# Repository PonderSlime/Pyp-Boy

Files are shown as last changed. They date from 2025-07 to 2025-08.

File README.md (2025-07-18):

# Pip-Boy
Fully-functional recreation of the pip boy from the Fallout franchise. This has features including:
- Pulse oximeter for heart rate
- GPS for location tracking
- RTL-SDR for hacking the radio waves

I decided to build this project because I had recently came across Fallout 4, which quickly rose to my top 5 video games list. When Highway was annouced, I decided I should build something from it. I had two options: build power armor (which would cost way too much, and is already being done by Hacksmith Industries), or the Pip-Boy (which is much more achievable for several reasons, cost included). Of course I chose the Pip-Boy, because It is still a really cool piece of tech. Another reason to build this was because I thought it would be really cool to navigate an entire system with just knobs, and one button.

**Onshape Link:** [https://cad.onshape.com/documents/fef0e9c1c845178b6cc354c6/w/e4e098e2dc3ae20b4478296f/e/bf3082dc19ffc9c7d7482000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](https://cad.onshape.com/documents/fef0e9c1c845178b6cc354c6/w/e4e098e2dc3ae20b4478296f/e/bf3082dc19ffc9c7d7482000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)

## Screenshots
Here's the 3D cad model:

https://hc-cdn.hel1.your-objectstorage.com/s/v3/2ecbe588889400ed564f8305abd84febf3086739_2025-06-28-181544_hyprshot.png

Here's the wiring diagram of the components used:

https://hc-cdn.hel1.your-objectstorage.com/s/v3/c522e84e316c760e37cd8d82a66ab6b510f91d17_2025-07-05-164655_hyprshot.png

## BOM:

| Part | Qty | Link | Price |
|---|-----|---|---|
| Raspberry Pi Zero 2 (Already have) | 1 | https://www.adafruit.com/piz2w | 16.50 |
| 4.0 Inch Waveshare HDMI Display | 1 | https://www.amazon.com/HDMI-LCD-Resolution-Resistive-Screen/dp/B07P5H2315 | 38.99 |
| V4 RTL-SDR Module | 1 | https://www.amazon.com/RTL-SDR-Blog-RTL2832U-Software-Defined/dp/B0CD745394 | 37.95 |
| GY-NEO6MV2 NEO-6M GPS Module | 1 | https://www.amazon.com/DWEII-GY-NEO6MV2-NEO6MV2-Control-Antenna/dp/B0BBM2H5TX/ | 8.99 |
| MAX10302 Pulse Oximeter | 1 | https://www.amazon.com/HiLetgo-MAX30102-Breakout-Oximetry-Solution/dp/B07QC67KMQ/ | 6.99 |
| Lithium Ion Battery - 3.7V 10050mAh | 1 | https://www.digikey.com/en/products/detail/adafruit-industries-llc/5035/14625568 | 29.95 |
| Power Boost 1000 Charger | 1 | https://www.digikey.com/en/products/detail/adafruit-industries-llc/2465/5356834 | 19.95 |
| EC12 Encoder | 5 | https://www.digikey.com/en/products/detail/alps-alpine/EC12E24204A2/19529077 | 8.40 |
| Push Button | 1 | https://www.digikey.com/en/products/detail/c-k/PVA1-OA-H1-1-2N-V2/417717 | 2.40 |
| 3mm Diameter 50mm Steel Dowel Pin | 2 | https://www.amazon.com/uxcell-Stainless-Support-Fasten-Elements/dp/B07MDFSJJ1 | 6.69 |
| 3mm Diameter 16mm Steel Dowel Pin | 2 | https://www.amazon.com/uxcell-Straight-Retaining-Stainless-Elements/dp/B01MQJAUUC | 6.69 |
| 3mm Diameter 7mm Steel Dowel Pin | 2 | https://www.amazon.com/HARFINGTON-Stainless-Cylindrical-Furniture-Installation/dp/B0F6CZV1MH | 6.09 |
| 3mm Diameter 36mm Steel Dowel Pin (Already have) | 1 | https://www.amazon.com/uxcell-Cylindrical-Mechanical-Manufacturing-Installation/dp/B0DRS9VZR4 | 6.99 |
| M3x4mmx5mm Heatset Inserts (Already have) | 6 | https://www.amazon.com/Threaded-Inserts-Printing-Components-Assortment/dp/B0DGQH7YX6 | 7.09 |
| M3 Screw Kit (whatever screw length works) (Already have) | 1 | https://www.amazon.com/Assortment-Stainless-Replacement-Machine-Fastener/dp/B0CMQG542V | 15.99 |
| 2 Gallon Polypropylene Container (for electroplating) | 1 | https://www.mcmaster.com/products/tubs/food-industry-plastic-storage-containers-6/material~polypropylene/ | 9.19 |
| Polypropylene Carboy (Copper Sulfate solution storage) | 1 | https://www.mcmaster.com/products/tanks/capacity~3-gal/carboys-1~/ | 31.29 |
| Copper sulfate Pentahydrate | 1 | https://www.amazon.com/Copper-Sulfate-Pentahydrate-Powder-Lbs/dp/B018W893PY/ | 22.95 |
| Distilled Water | 2 | https://www.walmart.com/ip/Pure-Life-Distilled-Water-1-Gallon-Plastic-Bottled-Water-1-Pack-Side-Handle/1070666864 | 2.38 |
| Distilled White Vinegar | 2 | https://www.walmart.com/ip/Great-Value-Distilled-White-Vinegar-128-fl-oz/10450998 | 3.94 |
| Metal Polish | 1 | https://www.amazon.com/Brasso-2660089334-Multi-Purpose-Metal-Polish/dp/B00D600PLA/ | 4.98 |
| ELECTRONICS+OTHER PARTS SUBTOTAL: | | | $189.89 |
| ELECTROPLATING SUBTOTAL (Can't do because of funds): | | | $79.67 |
| SUBTOTAL+ELECTROPLATING: | | | $269.56 |
| SUBTOTAL WITHOUT ELECTROPLATING: | | | $189.89 |
| TAX: | | | $21.99 |
| SUBTOTAL+SHIPPING/TAX: | | | 211.88 |
| WHAT I WILL BUY/ALREADY HAVE: | | | $68.56 |
| COST FOR HACK CLUB: | | | $143.32 (If this gets approved as 10 points, then I want to get the electroplating gear) |

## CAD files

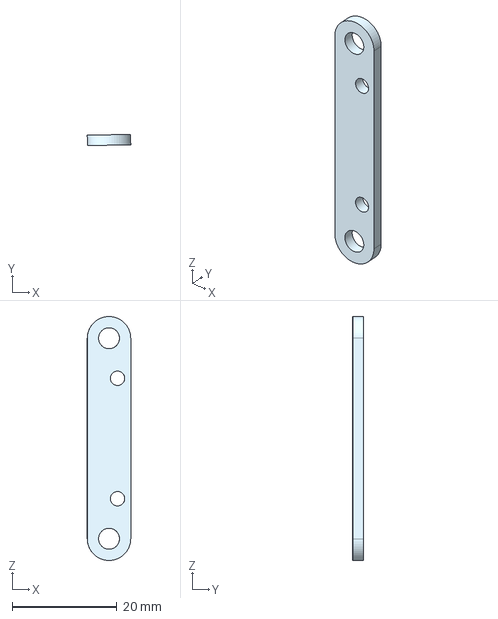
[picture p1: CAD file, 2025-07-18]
Pyp-Boy CAD Models/PyP-Boy Finished CAD Files/Part Studio 1 - RPI Zero Mounting Bracket 2.step
8.31 x 2.05 x 46.6 mm

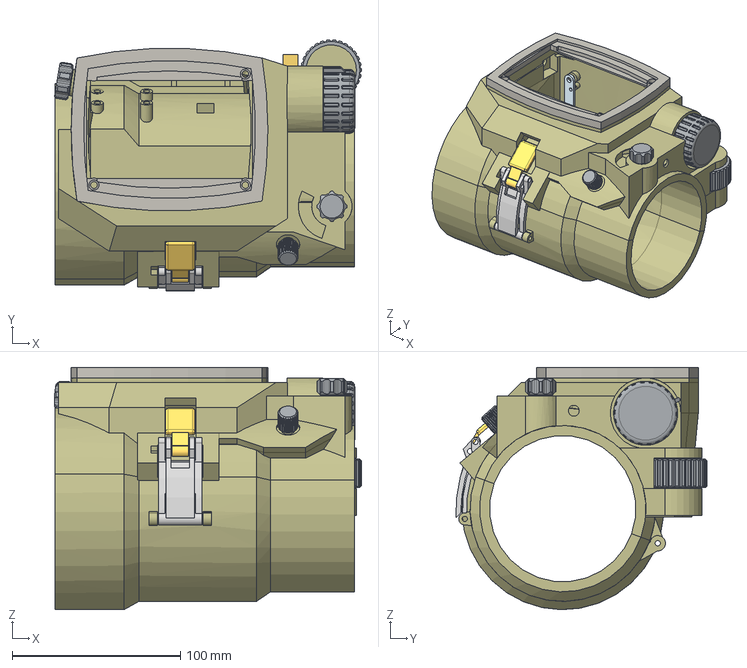
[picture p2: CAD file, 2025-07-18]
Pyp-Boy CAD Models/PyP-Boy FInished CAD Model.step
182.5 x 149.3 x 144.0 mm

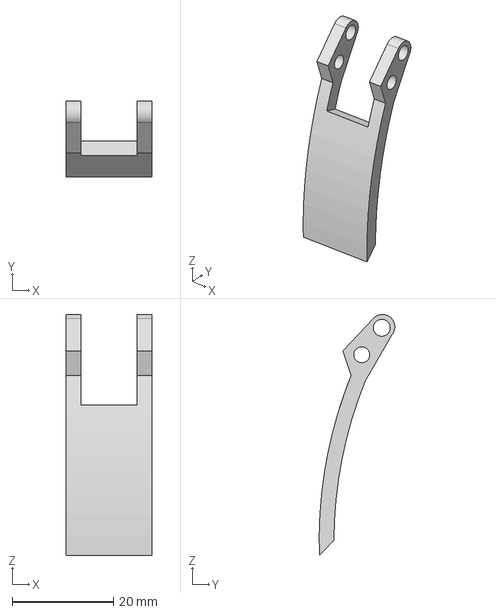
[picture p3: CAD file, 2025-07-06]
Pyp-Boy CAD Models/Part Studio 1 - Latch Handle.step
17.0 x 15.0 x 47.7 mm

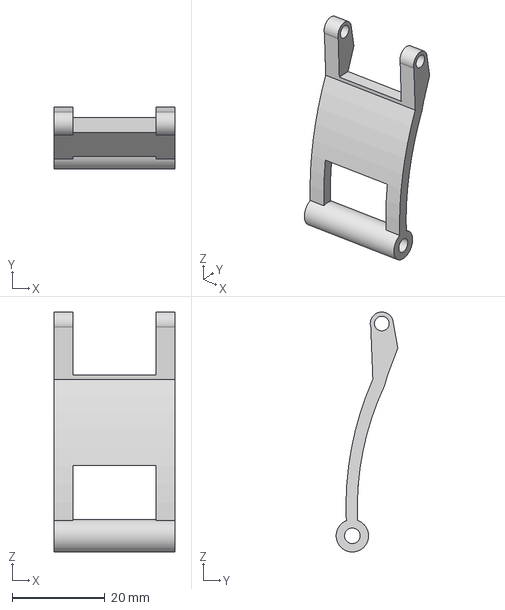
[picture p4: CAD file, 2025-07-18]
Pyp-Boy CAD Models/PyP-Boy Finished CAD Files/Part Studio 1 - Latch Base.step
26.0 x 13.3 x 51.8 mm

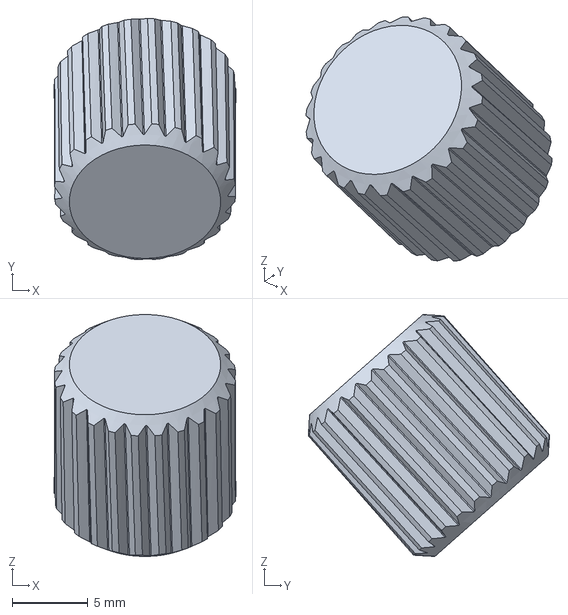
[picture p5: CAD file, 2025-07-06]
Pyp-Boy CAD Models/Part Studio 1 - Left-Right Control Knob.step
12.0 x 15.9 x 16.0 mm

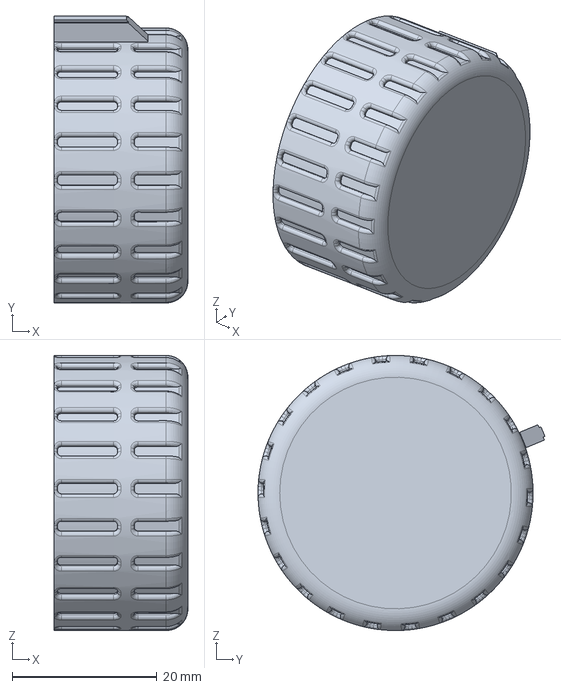
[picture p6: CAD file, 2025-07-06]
Pyp-Boy CAD Models/Part Studio 1 - Primary Menu Nav Wheel.step
18.5 x 39.6 x 38.0 mm

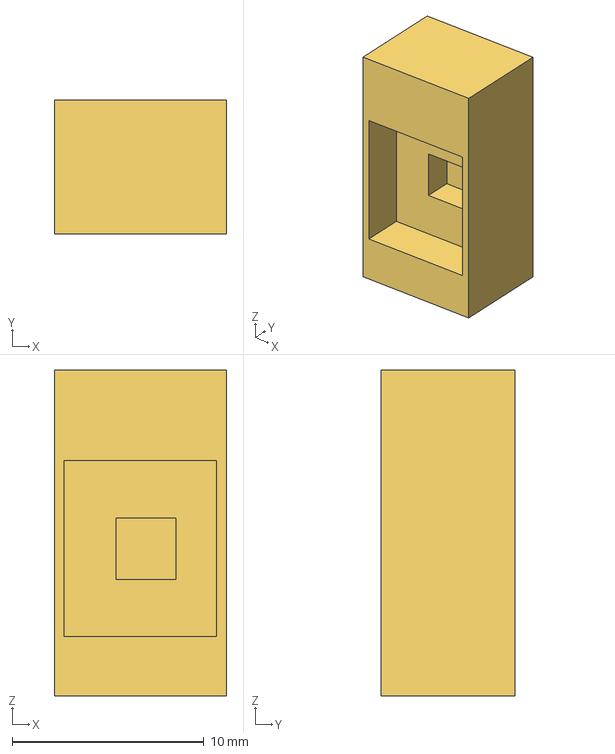
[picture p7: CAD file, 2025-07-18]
Pyp-Boy CAD Models/PyP-Boy Finished CAD Files/Part Studio 1 - Menu Select Button.step
9.00 x 7.00 x 17.0 mm

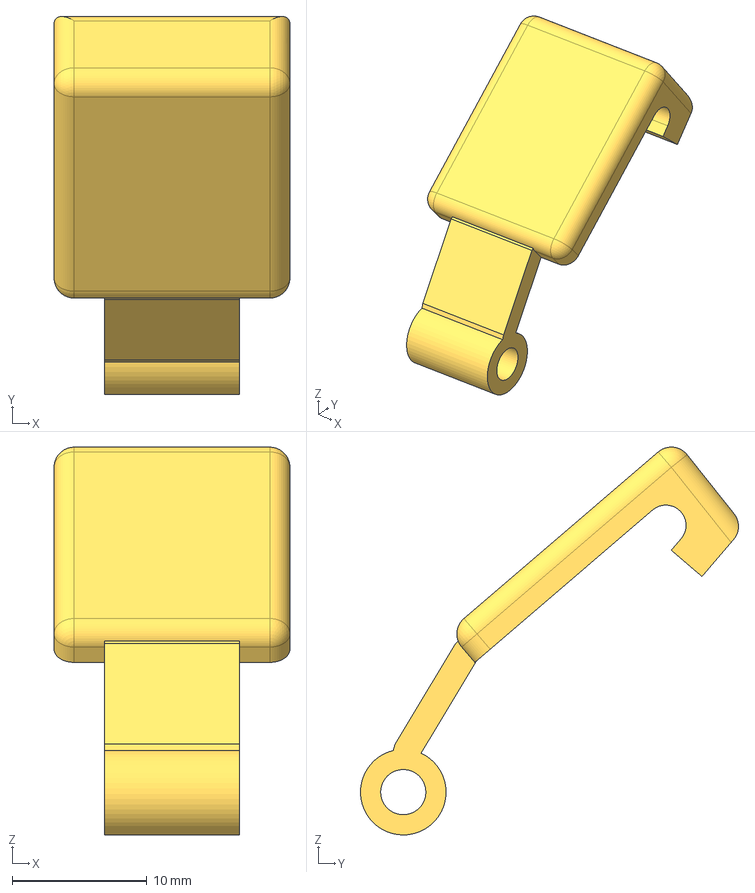
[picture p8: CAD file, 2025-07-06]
Pyp-Boy CAD Models/Part Studio 1 - Latch Hook.step
17.5 x 28.0 x 28.8 mm

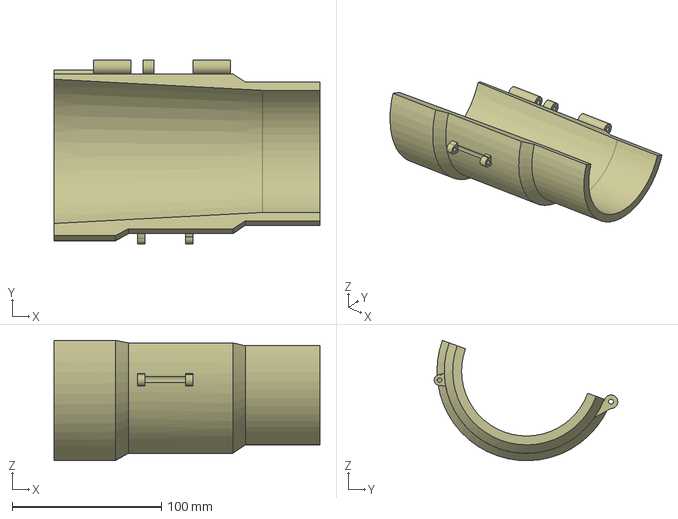
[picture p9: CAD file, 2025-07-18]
Pyp-Boy CAD Models/PyP-Boy Finished CAD Files/Part Studio 1 - Arm Back.step
178.0 x 122.9 x 80.5 mm

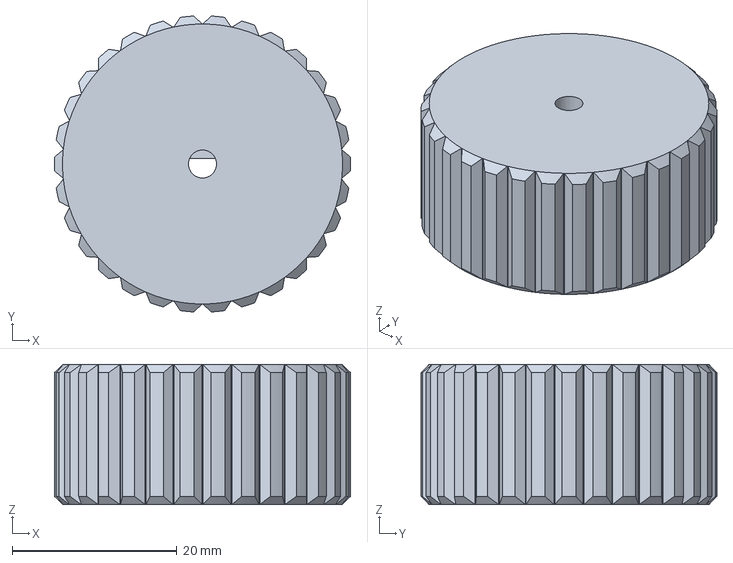
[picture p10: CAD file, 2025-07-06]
Pyp-Boy CAD Models/Part Studio 1 - Secondary Menu Nav Wheel.step
36.0 x 35.9 x 17.0 mm

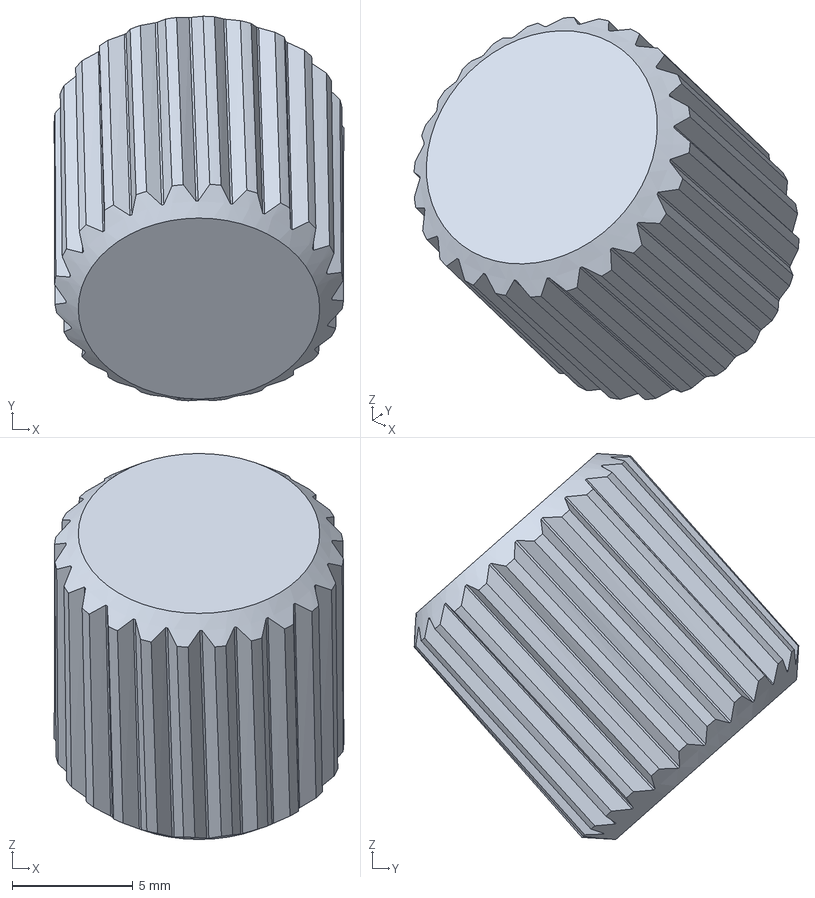
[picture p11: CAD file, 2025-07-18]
Pyp-Boy CAD Models/PyP-Boy Finished CAD Files/Part Studio 1 - Left-Right Control Knob.step
12.0 x 15.9 x 16.0 mm

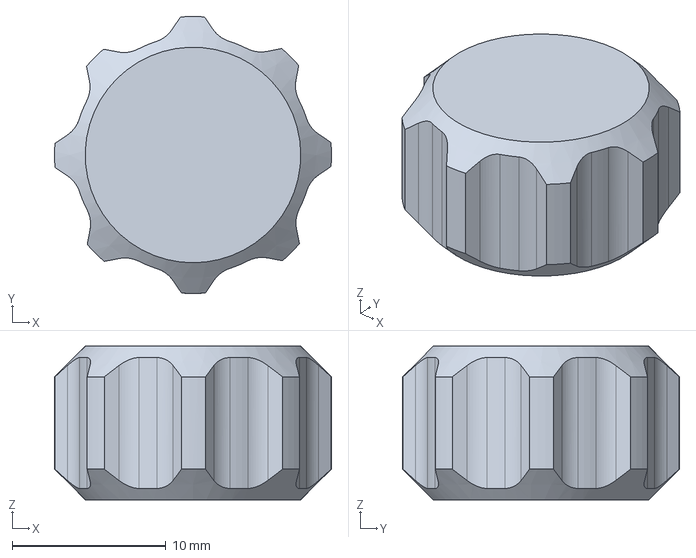
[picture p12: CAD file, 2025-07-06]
Pyp-Boy CAD Models/Part Studio 1 - Radio Tuner Dial.step
18.0 x 18.0 x 10.0 mm

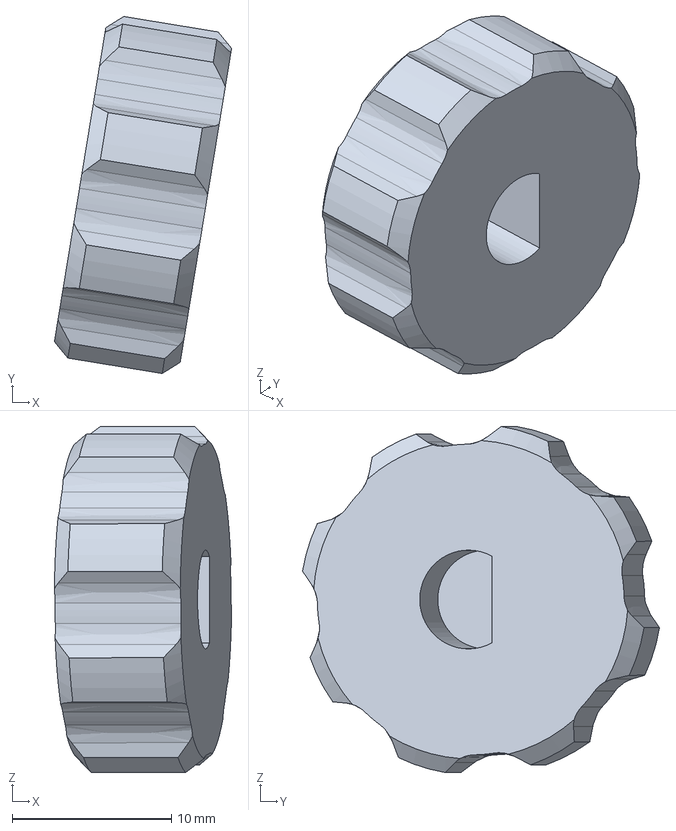
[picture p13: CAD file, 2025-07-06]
Pyp-Boy CAD Models/Part Studio 1 - Up-Down Control Knob.step
11.1 x 22.4 x 21.7 mm

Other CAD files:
Pyp-Boy CAD Models/PyP-Boy Finished CAD Files/Part Studio 1 - RPI Zero Mounting Bracket 1.step
Pyp-Boy CAD Models/PyP-Boy Finished CAD Files/Part Studio 1 - Latch Handle.step
Pyp-Boy CAD Models/Part Studio 1 - Latch Base.step
Pyp-Boy CAD Models/PyP-Boy Finished CAD Files/Part Studio 1 - Latch Hook.step
Pyp-Boy CAD Models/PyP-Boy Finished CAD Files/Part Studio 1 - Up-Down Control Knob.step
Pyp-Boy CAD Models/Part Studio 1 - Arm Back.step
Pyp-Boy CAD Models/PyP-Boy Finished CAD Files/Part Studio 1 - Arm Front.step
Pyp-Boy CAD Models/PyP-Boy Finished CAD Files/Part Studio 1 - Electronic Housing Rear Plate.step
Pyp-Boy CAD Models/PyP-Boy Finished CAD Files/Part Studio 1 - Electronic Housing.step
Pyp-Boy CAD Models/PyP-Boy Finished CAD Files/Part Studio 1 - Primary Menu Nav Wheel.step
Pyp-Boy CAD Models/PyP-Boy Finished CAD Files/Part Studio 1 - Radio Tuner Dial.step
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

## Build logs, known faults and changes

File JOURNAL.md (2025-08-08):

---
title: "Pyp-Boy"
author: "Micah Edwards"
description: "Fully-Functional recreation of the Pip-Boy 3000 Mark IV from Fallout 4"
created_at: "2025-05-22"
---
## Total time spent: 25h

# May 22nd-23rd: Started on Modeling the housing!

Did a bit of research on the size of the Pip Boy is, and started modeling it in Onshape.
I figured out how to use some tools I haven't used before, including the wrap tool and split tool. The base shape of the Pip-Boy is somewhat complete, but I still have a long way to go until I am done with the polished design (still need to add a ton of details, knobs, screw holes, vents, and many other things.)

https://hc-cdn.hel1.your-objectstorage.com/s/v3/68417295fe4105d7c07525d4ab1f006cc605584a_2025-05-23-143347_hyprshot.png

**Time spent: 3h**

# May 23rd-24th: Added some knobs!
I started to model where each of the knobs will go on the Pip-Boy. Also, I fixed some of the form factor of the overall arm section. I didn't really do a ton though

**Time spent: 2h**

# May 26th: Continuing knobby things
I added a knob for secondary menu selection and radio tuning, as well as a select button and a radio tuner indicator spot

https://hc-cdn.hel1.your-objectstorage.com/s/v3/095caf989e5443e84d2df1f08b7d26e1f4534526_2025-05-26-155143_hyprshot.png
https://hc-cdn.hel1.your-objectstorage.com/s/v3/43221945aa9acdee51f7f8d1b4c205f1dce9f17a_2025-05-26-155139_hyprshot.png

**Time spent: 2h**

# May 27th: Finished knobby stuff
I added both of the navigation wheels, as well as split apart the tube and electronics housing sections.

**Time spent: 1h**

# May 28th: Started Latch Mechanism, Arm Erginomics
I started work on the latch mecanism for the Pip-Boy, and also turned the cylendrical interior of the model into more of a cone shape.

https://hc-cdn.hel1.your-objectstorage.com/s/v3/961e35072b154a81121447986b809b8d1c70d7fe_2025-05-28-200431_hyprshot.png
https://hc-cdn.hel1.your-objectstorage.com/s/v3/486bc97e55d4ada4199406a0d993f4b2aa87ab2b_2025-05-28-200417_hyprshot.png

**Time spent: 1h**

# June 27th: Back From Break, Finished Latch Mechanism & Hinges, Added Encoder and Heatset Mounting Holes
I finally got the motivation to continue working on my project. I finished uo the latch mechanism and the upper hinge with some 3mm rods. Also, I added spots for the encoders on all of the knobs. In addition, I added a handful of heatset holes that are hidden from the frontside to secure it together.

https://hc-cdn.hel1.your-objectstorage.com/s/v3/b2e52c3f80351a633573ffb4218ada6e2fc150f8_2025-06-27-203610_hyprshot.png
https://hc-cdn.hel1.your-objectstorage.com/s/v3/75f5c39bce37d8ea9c7e3828193f0c434625de04_2025-06-27-203554_hyprshot.png
https://hc-cdn.hel1.your-objectstorage.com/s/v3/76d50b34b40de67969643d15641455e24a616dab_2025-06-27-203549_hyprshot.png

**Time spent: 4h**

# June 28th: Added Texture to the Knobs, did Research on RTL-SDR Modules
I added some nice details to each of the knobs, and gave them cool grips. Also, I fixed the latch tolerances so they actually work, and did some research on how I could get FM radio recieving on my device.
https://hc-cdn.hel1.your-objectstorage.com/s/v3/2ecbe588889400ed564f8305abd84febf3086739_2025-06-28-181544_hyprshot.png

**Time spent: 3h**

# June 29th: Started Work on a BOM, Added Latch Pin Slot, Manufacturing Research
Today I decided to start working on a bill of materials for my project. I also took some time to figure out where/how I should get the case manufactured. After trying several CNC companies' auto quote, I determined that it would be way too expensive ($30.00 USD for just one simple latch part!). Instead, I will 3D print the parts and electroplate it at home. The only change I made to the CAD model today was adding a latch pin slot so that the latch can actually lock properly.

https://hc-cdn.hel1.your-objectstorage.com/s/v3/1c74663c2242f76f8d4dc3c0941211fc3dfbe883_2025-06-29-171235_hyprshot.png

**Time spent: 2h**

# July 1-2nd: Started work on pyp-tui
I decided that I wanted to code a TUI (terminal user interface) using rust, to use as the main interface for my device. So far I have a basic inventory database, menus, and submenus. It still need some controls for the RTL-SDR module though.

https://hc-cdn.hel1.your-objectstorage.com/s/v3/79f344e348c653453cdb9142933b67766726bf15_2025-07-02-152713_hyprshot.png

**Time spent: 2h**

# July 3-4: Working on Organization, Adding Map Data
I decided to start organizing my script, by breaking it up into seperate files. Also, I was able to finally get the map data stuff working. Origonally, I was going to go for a ascii art map centered on the coordinates from the gps module, but I couldn't get that working. It will just be data instead. And the best part? It works offline, with a small library size! Also, I implemented an escape button that erases any evidence of the tui being open! In addition, I fixed the inventory tabs so that they change content based on category.

https://github.com/user-attachments/assets/03545f6d-08a7-4fc2-ad75-7554e2540552

**Time spent: 5h**

# July 16-20: Case Design Fixes and Assembly
I finally got all the parts for my project! I started by fixing all of my case design files so that they could fit my components. This took about four hours, and I modified the encoder holes so they could fit more snugly, added mounting posts for the raspberry pi and gps module, and added a nice cutout for my battery and wiring stuff. I also worked a bit on assembling my project, and got everything put together!

https://hc-cdn.hel1.your-objectstorage.com/s/v3/0b8f877d28e4e5ec8f6f84db51e3453ea9cfeb9f_2025-07-20-210547_hyprshot.png
https://hc-cdn.hel1.your-objectstorage.com/s/v3/38d9a39f9074412fb17914c7675049f7af02daad_2025-07-20-210528_hyprshot.png





**Time spent: 7h**

# August 5-7th: Finished Assembly
I finally finished assembly, after getting the last part for the screen. Also, I fixed the inventory system's quantity system, because it had a glitch with the differences between the json and the filtered lists. 

**Time spent: 1h**

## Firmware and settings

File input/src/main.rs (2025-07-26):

// src/main.rs

use rppal::gpio::{Gpio, InputPin, Level};

use evdev::{Key, InputEvent, EventType, AttributeSet}; // Add AttributeSet import
use evdev::uinput::{VirtualDevice, VirtualDeviceBuilder};

use std::sync::{Arc, Mutex};
use std::time::{Duration, Instant};
use std::thread;
use anyhow::{Result, Context};
use log::{info, debug};
use env_logger;

// Define GPIO pins for each encoder and the main button
const ENCODER_PINS: [(u8, u8); 5] = [
    (17, 27), // Encoder 1: Out A (CLK), Out B (DT)
    (23, 24), // Encoder 2
    (5, 6),   // Encoder 3
    (19, 26), // Encoder 4
    (20, 21), // Encoder 5
];

const MAIN_BUTTON_PIN: u8 = 10; // For the 2-pin button

// Structure to hold encoder state
struct Encoder {
    pin_a: InputPin,
    pin_b: InputPin,
    last_state_a: Level,
}

impl Encoder {
    fn new(gpio: &Gpio, pin_a_num: u8, pin_b_num: u8) -> Result<Self> {
        // Use into_input_pullup() directly on the Pin to set pull-up and convert to InputPin
        let pin_a = gpio.get(pin_a_num)?.into_input_pullup();
        let pin_b = gpio.get(pin_b_num)?.into_input_pullup();

        let initial_state_a = pin_a.read();

        Ok(Encoder {
            pin_a,
            pin_b,
            last_state_a: initial_state_a,
        })
    }

    fn update(&mut self) -> Option<i8> {
        let current_state_a = self.pin_a.read();
        let current_state_b = self.pin_b.read();

        if current_state_a != self.last_state_a {
            self.last_state_a = current_state_a;
            if current_state_a == Level::Low {
                if current_state_b == Level::Low {
                    return Some(1); // Clockwise
                } else {
                    return Some(-1); // Counter-clockwise
                }
            }
        }
        None
    }
}


fn main() -> Result<()> {
    env_logger::Builder::from_env(env_logger::Env::default().default_filter_or("info")).init();
    info!("Starting Raspberry Pi Encoder Input service...");

    let gpio = Gpio::new().context("Failed to initialize GPIO")?;

    // --- Setup Encoders ---
    let mut encoders: Vec<Encoder> = Vec::with_capacity(ENCODER_PINS.len());
    for (i, &(pin_a_num, pin_b_num)) in ENCODER_PINS.iter().enumerate() {
        let encoder = Encoder::new(&gpio, pin_a_num, pin_b_num)
            .with_context(|| format!("Failed to set up encoder {}", i + 1))?;
        encoders.push(encoder);
        info!("Encoder {} (GPIO {}/{}) configured.", i + 1, pin_a_num, pin_b_num);
    }

    // --- Setup Main Button ---
    // Use into_input_pullup() directly on the Pin to set pull-up and convert to InputPin
    let main_button_pin = gpio.get(MAIN_BUTTON_PIN)?.into_input_pullup();
    info!("Main Button (GPIO {}) configured.", MAIN_BUTTON_PIN);

    // --- Setup evdev Virtual Device ---
    let uinput_device = Arc::new(Mutex::new(
        VirtualDeviceBuilder::new()?
            .name("EC12 Multi-Encoder Keyboard")
	    // Use AttributeSet::from_iter for with_keys in 0.12.2
            .with_keys(&AttributeSet::from_iter(vec![
                // Encoder 1: Left/Right
                Key::KEY_LEFT, Key::KEY_RIGHT,
                // Encoder 2: Up/Down
                Key::KEY_UP, Key::KEY_DOWN,
                // Encoder 3: A/D
                Key::KEY_A, Key::KEY_D,
                // Encoder 4: W/S
                Key::KEY_W, Key::KEY_S,
                // Encoder 5: KPPLUS/KPMINUS
                Key::KEY_KPPLUS, Key::KEY_KPMINUS,
                // Main Button: Enter
                Key::KEY_ENTER,
            ]))?
            .build()
            .context("Failed to build virtual device")?
    ));
    info!("Virtual input device created.");

    // --- Event loop for Encoders ---
    let mut handles = Vec::new();
    for (i, mut encoder) in encoders.into_iter().enumerate() {
        let uinput_device_clone: Arc<Mutex<VirtualDevice>> = Arc::clone(&uinput_device);
        let key_map = match i {
            0 => (Key::KEY_LEFT, Key::KEY_RIGHT), // Encoder 1: Left/Right
            1 => (Key::KEY_UP, Key::KEY_DOWN),    // Encoder 2: Up/Down
            2 => (Key::KEY_A, Key::KEY_D),        // Encoder 3: A/D
            3 => (Key::KEY_W, Key::KEY_S),        // Encoder 4: W/S
            4 => (Key::KEY_KPPLUS, Key::KEY_KPMINUS), // Encoder 5: KPPLUS/KPMINUS
            _ => unreachable!(),
        };

        let handle = thread::spawn(move || -> Result<()> {
            let mut last_detection_time = Instant::now();
            let debounce_delay = Duration::from_millis(5);

            loop {
                thread::sleep(Duration::from_micros(100));

                if last_detection_time.elapsed() < debounce_delay {
                    continue;
                }

                if let Some(direction) = encoder.update() {
                    let mut device = uinput_device_clone.lock().unwrap();
                    if direction == 1 {
                        debug!("Encoder {} Clockwise: {:?}", i + 1, key_map.0);
                        device.emit(&[
                            InputEvent::new(EventType::KEY, key_map.0.0, 1), // Pass EventType::KEY directly
                            InputEvent::new(EventType::KEY, key_map.0.0, 0), // Pass EventType::KEY directly
                        ])?;
                    } else {
                        debug!("Encoder {} Counter-Clockwise: {:?}", i + 1, key_map.1);
                        device.emit(&[
                            InputEvent::new(EventType::KEY, key_map.1.0, 1), // Pass EventType::KEY directly
                            InputEvent::new(EventType::KEY, key_map.1.0, 0), // Pass EventType::KEY directly
                        ])?;
                    }
                    last_detection_time = Instant::now();
                }
            }
        });
        handles.push(handle);
    }

    // --- Event loop for Main Button ---
    let uinput_device_clone: Arc<Mutex<VirtualDevice>> = Arc::clone(&uinput_device);
    let button_handle = thread::spawn(move || -> Result<()> {
        let mut last_state = main_button_pin.read();
        let mut last_press_time = Instant::now();
        let debounce_delay = Duration::from_millis(50);

        loop {
            thread::sleep(Duration::from_millis(10));
            let current_state = main_button_pin.read();

            if current_state != last_state {
                if last_press_time.elapsed() < debounce_delay {
                    continue;
                }

                last_state = current_state;
                if current_state == Level::Low { // Button pressed (pulled to ground)
                    info!("Main Button Pressed: KEY_ENTER!");
                    let mut device = uinput_device_clone.lock().unwrap();
                    device.emit(&[
                        InputEvent::new(EventType::KEY, Key::KEY_ENTER.0, 1), // Pass EventType::KEY directly
                        InputEvent::new(EventType::KEY, Key::KEY_ENTER.0, 0), // Pass EventType::KEY directly
                    ])?;
                }
                last_press_time = Instant::now();
            }
        }
    });
    handles.push(button_handle);


    // Wait for all threads to finish (they won't in this case, it's a daemon)
    for handle in handles {
        handle.join().expect("Thread panicked")?;
    }

    info!("Service stopped.");
    Ok(())
}

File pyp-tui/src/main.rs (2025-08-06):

use chrono::prelude::*;
use crossterm::{
    event::{self, DisableMouseCapture, EnableMouseCapture, Event as CEvent, KeyCode},
	execute,
    terminal::{disable_raw_mode, enable_raw_mode, EnterAlternateScreen, LeaveAlternateScreen},
};
use rand::{distributions::Alphanumeric, prelude::*};

use std::fs;
use std::io;
use std::sync::mpsc;
use std::thread;
use std::time::{Duration, Instant};
use std::error::Error as StdError;
use thiserror::Error;
use ratatui::{
    backend::CrosstermBackend,
    layout::{Alignment, Constraint, Direction, Layout},
    style::{Color, Modifier, Style},
    text::{Span, Line, Text},
    widgets::{Block, BorderType, Borders, ListState, Paragraph, Tabs},
    Terminal,
    Frame,
};

use gpsd_client::*;

extern crate linux_embedded_hal as hal;
extern crate max3010x;
extern crate ratatui;

use max3010x::{Max3010x, Led, SampleAveraging};

const DB_PATH: &str = "./data/db.json";

mod render_tabs;
mod menus;
mod kb;

use render_tabs::{render_map, render_stat, render_data, render_inv, read_db, get_map_data, Item, add_item_to_db, show_quantity_selector,};
use menus::{MenuItem, StatSubMenu, InvSubMenu, DataSubMenu};

#[derive(Error, Debug)]
pub enum Error {
    #[error("error reading the DB file: {0}")]
    ReadDBError(#[from] io::Error),
    #[error("error parsing the DB file: {0}")]
    ParseDBError(#[from] serde_json::Error),
}

enum Event<I> {
    Input(I),
    Tick,
}
#[derive(Debug, PartialEq)]
pub struct Coordinates {
    pub latitude: f64,
    pub longitude: f64,
}
pub fn get_current_coordinates_array() -> Result<[f64; 2], Box<dyn StdError>> {
    let mut gps = GPS::connect()
    	.map_err(|e| Box::<dyn StdError>::from(format!("GPS connect error: {:?}", e)))?;
	let data: GPSData = gps.current_data()
    	.map_err(|e| Box::<dyn StdError>::from(format!("GPS data error: {:?}", e)))?;
	if data.lat.is_finite() && data.lon.is_finite() {
    	Ok([data.lat, data.lon])
	} else {
		Err(Box::new(io::Error::new(
			io::ErrorKind::NotFound,
			"Latitude or longitude invalid in GPS data",
		)))
	}
}
fn main() -> Result<(), Box<dyn std::error::Error>> {
	
	let coords: [f64; 2] = match get_current_coordinates_array() {
        Ok(c) => c,
        Err(e) => {
            eprintln!("Error getting coordinates: {}", e);
            [0.0, 0.0]
        }
    };

	let mut map_data: Option<String> = None;
	let mut start_time = Instant::now();
    let one_minute = Duration::from_secs(60);

	if map_data.is_none() || start_time.elapsed() >= one_minute {
		start_time = Instant::now();
        map_data = Some(get_map_data(coords));
		println!("getting map data: {:?}", map_data)
    }

	let stat_submenu_titles = vec!["GENERAL", "STATUS", "SETTINGS"];
	let inv_submenu_titles = vec!["WEAPONS", "APPAREL", "AID", "MISC", "JUNK", "MODS", "AMMO"];
	let data_submenu_titles = vec!["QUESTS", "WORKSHOPS", "STATS"];

	let mut active_stat_submenu = StatSubMenu::General;
	let mut active_inv_submenu = InvSubMenu::Weapons;
	let mut active_data_submenu = DataSubMenu::Quests;


    enable_raw_mode().expect("can run in raw mode");
	let mut stdout = io::stdout();

	execute!(stdout, EnterAlternateScreen, EnableMouseCapture)?;
	

    let (tx, rx) = mpsc::channel();
    let tick_rate = Duration::from_millis(200);
    thread::spawn(move || {
        let mut last_tick = Instant::now();
        loop {
            let timeout = tick_rate
                .checked_sub(last_tick.elapsed())
                .unwrap_or_else(|| Duration::from_secs(0));

            if event::poll(timeout).expect("poll works") {
                if let CEvent::Key(key) = event::read().expect("can read events") {
                    tx.send(Event::Input(key)).expect("can send events");
                }
            }

            if last_tick.elapsed() >= tick_rate {
                if let Ok(_) = tx.send(Event::Tick) {
                    last_tick = Instant::now();
                }
            }
        }
    });

    let stdout = io::stdout();
    let backend = CrosstermBackend::new(stdout);
    let mut terminal = Terminal::new(backend)?;
    terminal.clear()?;

    let menu_titles = vec!["STAT", "INV", "DATA", "MAP", "RADIO"];
    let mut active_menu_item = MenuItem::Stat;
    let mut inv_list_state = &mut ListState::default();
    inv_list_state.select(Some(0));

	/* let dev = hal::I2cdev::new("/dev/i2c-1").unwrap();

	let mut sensor = Max3010x::new_max30102(dev);
	let mut sensor = sensor.into_heart_rate().unwrap();
	sensor.set_sample_averaging(SampleAveraging::Sa4).unwrap();
	sensor.set_pulse_amplitude(Led::All, 15).unwrap();
	sensor.enable_fifo_rollover().unwrap();

	let mut data = [0; 3];
	let samples_read = sensor.read_fifo(&mut data).unwrap();

  	let dev = sensor.destroy(); */

    loop {
		terminal.clear();
        terminal.draw(|rect| {
            let size = rect.area();
			
            let chunks = Layout::default()
                .direction(Direction::Vertical)
                .margin(2)
                .constraints(
                    [
                        Constraint::Length(3),
                        Constraint::Min(2),
                        Constraint::Length(3),
                    ]
                    .as_ref(),
                )
                .split(size);
			
            let copyright = Paragraph::new("COPYRIGHT 2075 ROBCO(R)")
                .style(Style::default().fg(Color::LightCyan))
                .alignment(Alignment::Center)
                .block(
                    Block::default()
                        .borders(Borders::ALL)
                        .style(Style::default().fg(Color::White))
                        .title("COPYRIGHT")
                        .border_type(BorderType::Plain),
                );

            let menu: Vec<Line> = menu_titles
                .iter()
                .map(|t| {
                    let (first, rest) = t.split_at(1);
                    Line::from(vec![
                        Span::styled(
                            first,
                            Style::default()
                                .fg(Color::Yellow)
                                .add_modifier(Modifier::UNDERLINED),
                        ),
                        Span::styled(rest, Style::default().fg(Color::White)),
                    ])
                })
                .collect();
			
            let tabs = Tabs::new(menu)
                .select(Some(active_menu_item.into()))
                .block(Block::default().title("STAT").borders(Borders::ALL))
                .style(Style::default().fg(Color::White))
                .highlight_style(Style::default().fg(Color::Yellow))
                .divider(Span::raw("|"));
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

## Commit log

2025-06-28 Got back from break, finished hinges and encoder knob mountings
2025-06-29 June 28th: Added Texture to Knobs, Fixed Hinge Tolerances
2025-06-29 Added Initial BOM.csv
    [BOM.csv]
2025-06-29 June 29th: Added Latch Pin Slot
2025-07-04 Reverted OSM_Geo_Mapper, using data-based mapping (timezones added)
    [main.rs]
2025-07-05 Added "+ Add New" button to inventory
2025-07-06 Added Wiring, first full BOM
    [BOM.csv, Pip Boy wiring.kicad_pcb, Pip Boy wiring.kicad_sch]
2025-07-06 Auto stash before merge of "main" and "origin/main"
    [BOM.csv]
2025-07-06 Fixed something on the total bar
    [BOM.csv]
2025-07-06 Fixed final price guestimate (excluding shipping :C )
    [BOM.csv]
2025-07-06 Added all cad models from Onshape, did more number crunching for price
    [BOM.csv, Part Studio 1 - Arm Back.step, Part Studio 1 - Arm Front.step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]
2025-07-06 Fixed prices to match that of a 6-point project, added full step file
    [BOM.csv, Pyp-Boy CAD Model.step]
2025-07-06 Fixed error in BOM.csv line 13
    [BOM.csv]
2025-07-06 Fixed another error in BOM.csv
    [BOM.csv]
2025-07-06 Updated README.md BOM Table
2025-07-18 Finished adding all mounting points to CAD Model
    [Part Studio 1 - Arm Back.step, Part Studio 1 - Arm Front.step, Part Studio 1 - Electronic Housing Rear Plate.step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]
2025-07-19 Partially completed keyboard in tui, added encoders to wiring diagram
    [Pip Boy wiring.kicad_sch]
2025-07-21 Assembled Project!
2025-07-21 Added assembly pictures to JOURNAL.md
2025-07-26 Added input firmware from the pi
    [BOM.csv]
2025-08-06 Fixed issues with inventory quantity modifying the incorrect item
    [main.rs]
